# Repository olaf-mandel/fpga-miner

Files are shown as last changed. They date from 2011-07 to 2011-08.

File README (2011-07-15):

This project is concerned with mining Bitcoins via FPGAs.
For Details, see:

FPGA-Firmware:
http://forum.bitcoin.org/index.php?topic=9047.0

Hardware:
http://forum.bitcoin.org/index.php?topic=9047.0

The subdirectories (will at some unspecified point in the future) contain the
design files for the mining hardware, the firmware and the software.

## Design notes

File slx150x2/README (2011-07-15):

This directory contains the design for a hybrid FPGA board that can be
used both stand along as well as together with a packplane. The board
features two Xilinx Spartan 6 XC6SLX150-3FGG484C and one TI MSP430F55xx
MCU.

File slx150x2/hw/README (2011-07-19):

This directory is reserved for the hardware design.

Current contents:

* FPGAcomp.lib    : Eagle library containing custom components for design
* pcbcart.dru     : Eagle design rules file applied to the board
* FPGA_pin_demo.* : A design with two XC6SLX150 in the FGG484 package. No
                    power supply, interface logic or connectors.

The FPGA_pin_demo shows how to connect the different parts of the FPGA and
routes all signals on a 4-layer PCB. The minimum sizes are taken from the
discussion on the forum.

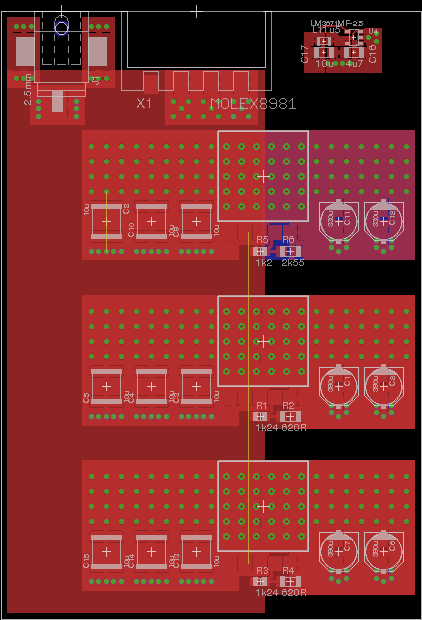
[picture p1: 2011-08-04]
slx150x2/hw/PSU.png

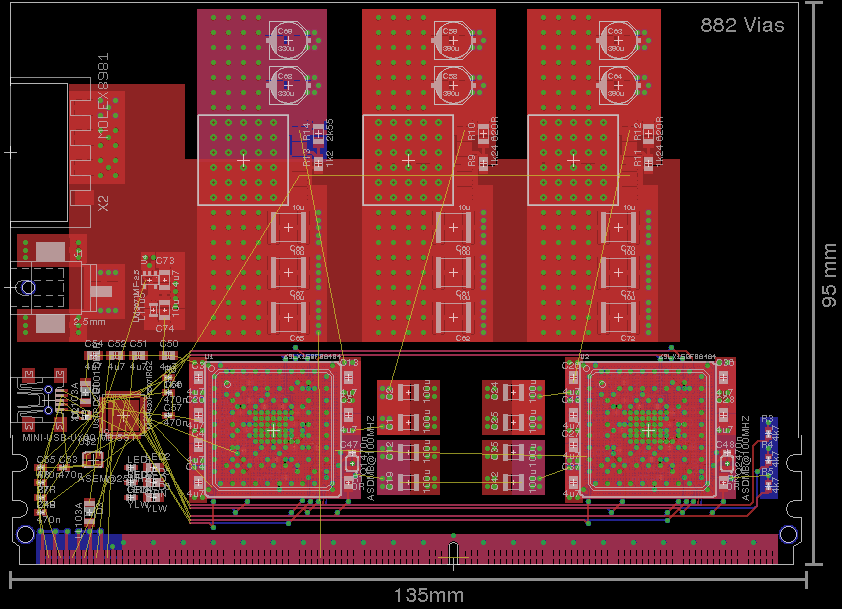
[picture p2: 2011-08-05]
slx150x2/hw/merged.png

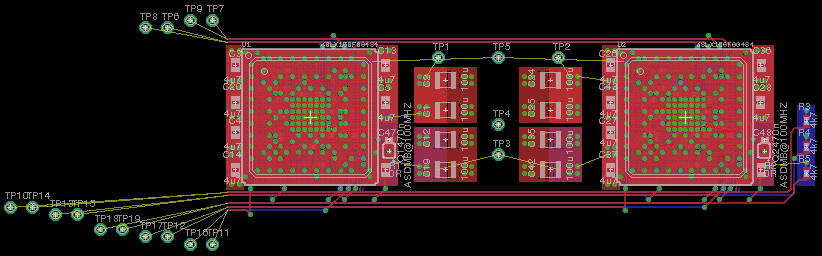
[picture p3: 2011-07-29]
slx150x2/hw/FPGA.png

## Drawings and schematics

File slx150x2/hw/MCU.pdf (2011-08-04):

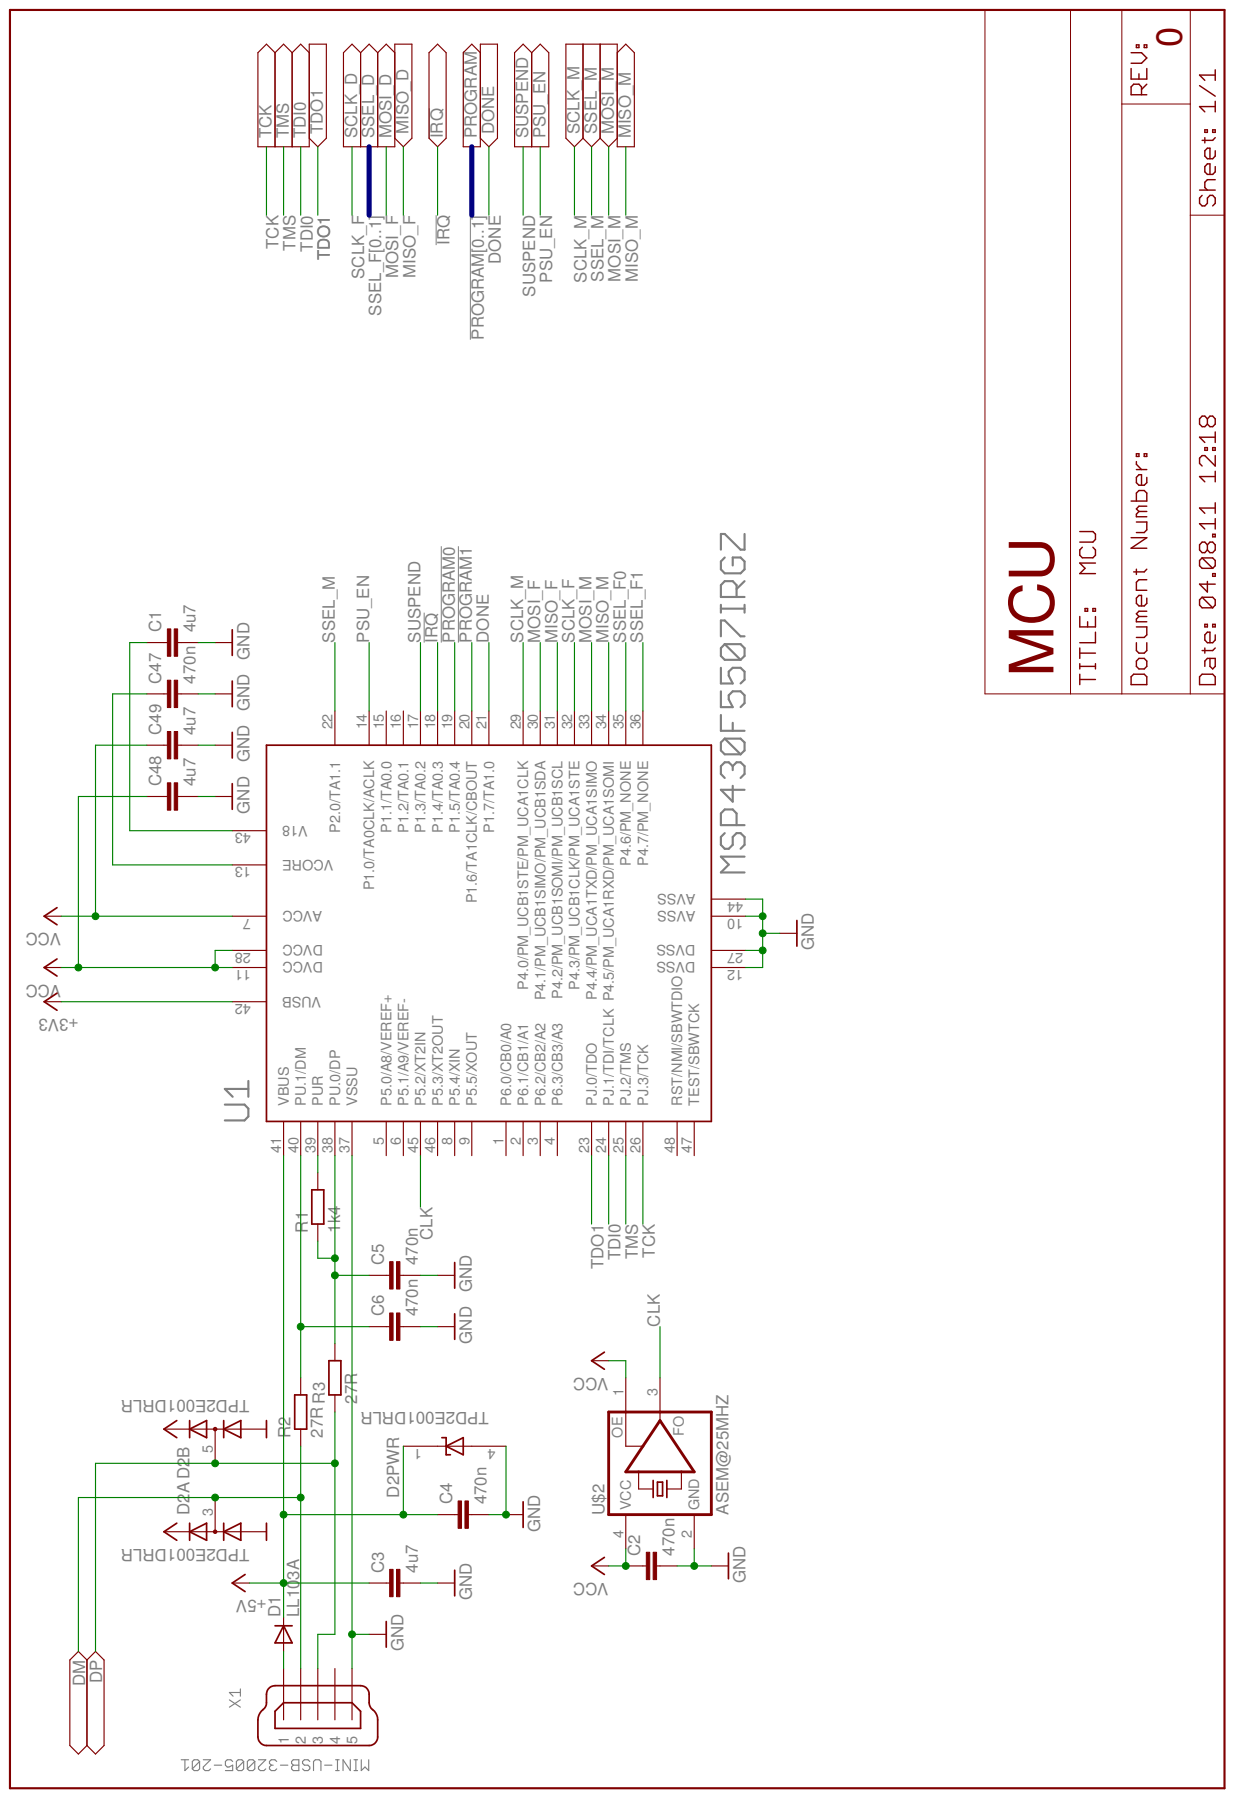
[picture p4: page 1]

470n 4u7 4u7 1k4 ASEM@25MHZ GND GND GND GND 4u7 GND CCV CCV GND GND CCV 470n CCV 4u7 GND 470n GND LL103A 27R 27R 470n GND 470n GND RL RD100E2 DPT RL RD100E2 DPT RL RD100E2 DPT 3V3+DMDP TCK TMS TDI0 TDO1 SCLK_D SSEL_D MOSI_D MISO_D IRQ PROGRAM DONE SUSPEND PSU_EN MISO_M SSEL_M SCLK_M MOSI_M V5+ P6.0/CB0/A0 1 P6.1/CB1/A1 2 P6.2/CB2/A2 3 P6.3/CB3/A3 4 P5.0/A8/VEREF+ 5 P5.1/A9/VEREF- 6 CCVA 7 P5.4/XIN 8 P5.5/XOUT 9 SSVA 01 CCVD 11 SSVD 21 EROCV 31 P1.0/TA0CLK/ACLK 14 CCVD 82 SSVD 72 PJ.3/TCK 26 PJ.2/TMS 25 PJ.1/TDI/TCLK 24 PJ.0/TDO 23 P2.0/TA1.1 22 P1.7/TA1.0 21 P1.6/TA1CLK/CBOUT 20 P1.5/TA0.4 19 P1.4/TA0.3 18 P1.3/TA0.2 17 P1.2/TA0.1 16 P1.1/TA0.0 15 P4.0/PM_UCB1STE/PM_UCA1CLK 29 P4.1/PM_UCB1SIMO/PM_UCB1SDA 30 P4.2/PM_UCB1SOMI/PM_UCB1SCL 31 P4.3/PM_UCB1CLK/PM_UCA1STE 32 P4.4/PM_UCA1TXD/PM_UCA1SIMO 33 P4.5/PM_UCA1RXD/PM_UCA1SOMI 34 P4.6/PM_NONE 35 P4.7/PM_NONE 36 VSSU 37 PU.0/DP 38 PUR 39 PU.1/DM 40 VBUS 41 BSUV 24 81V 34 SSVA 44 P5.2/XT2IN 45 P5.3/XT2OUT 46 TEST/SBWTCK 47 RST/NMI/SBWTDIO 48 C47 C48 C49 12345 R1 42 3 U$2 GND VCC 1 FOOE C1 C2 C3 C4 D1 R2 R3 C5 C6 D2A 3 D2B51 4 D2PWR PROGRAM[0..1] SSEL_F[0..1] CLK CLK TCK TCK DONE DONE TMS TMS TDI0 TDI0 TDO1 TDO1 IRQ IRQ SUSPEND SUSPEND PSU_EN PSU_EN SCLK_F SCLK_F MOSI_F MOSI_F MISO_F MISO_F SSEL_M SSEL_M MOSI_M MOSI_M MISO_M MISO_M SCLK_M SCLK_M SSEL_F0 SSEL_F1 PROGRAM1 PROGRAM0 0 MCU

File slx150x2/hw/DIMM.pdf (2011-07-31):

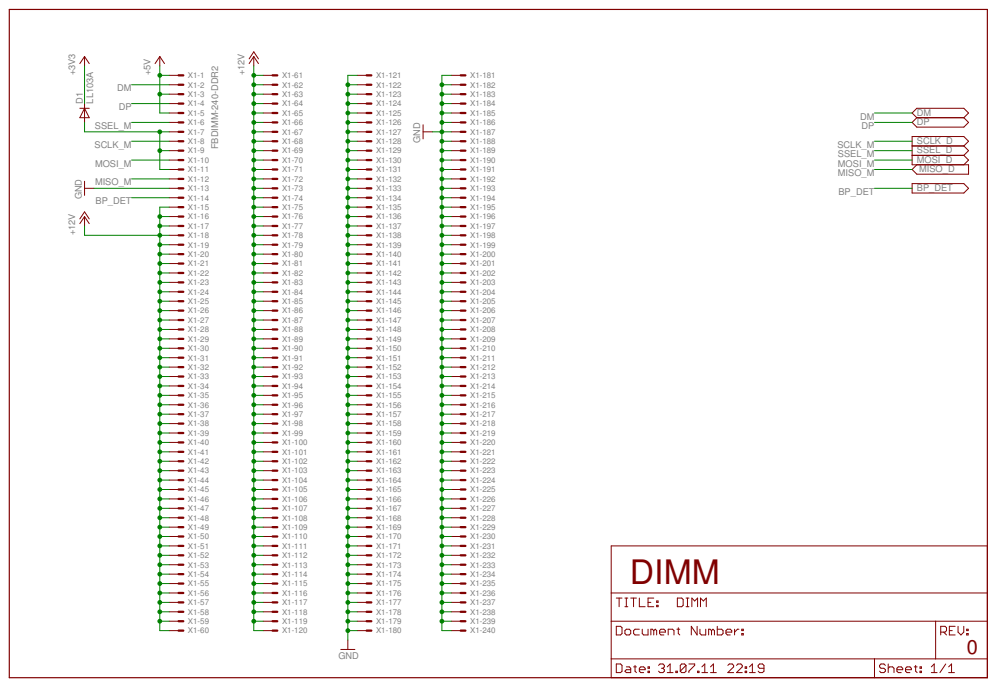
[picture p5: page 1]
FBDIMM-240-DDR2+12V; GND; SCLK_D SSEL_D M OSI_D MISO_D; DPDM; BP_DET; SSEL_M; SCLK_M; OSI_M; MISO_M; DIM

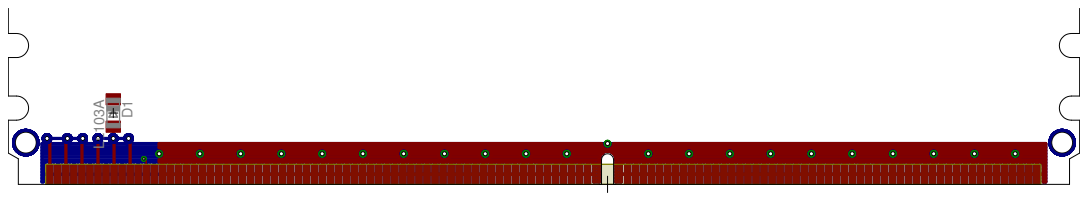
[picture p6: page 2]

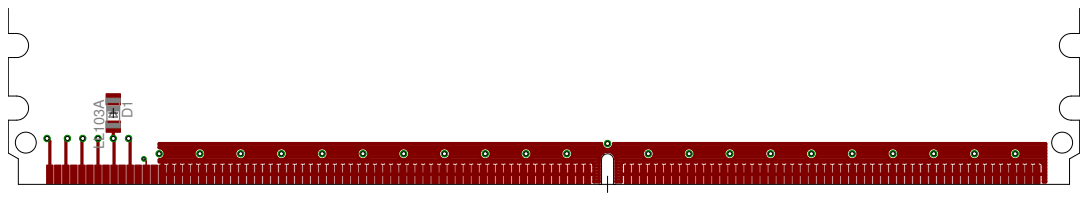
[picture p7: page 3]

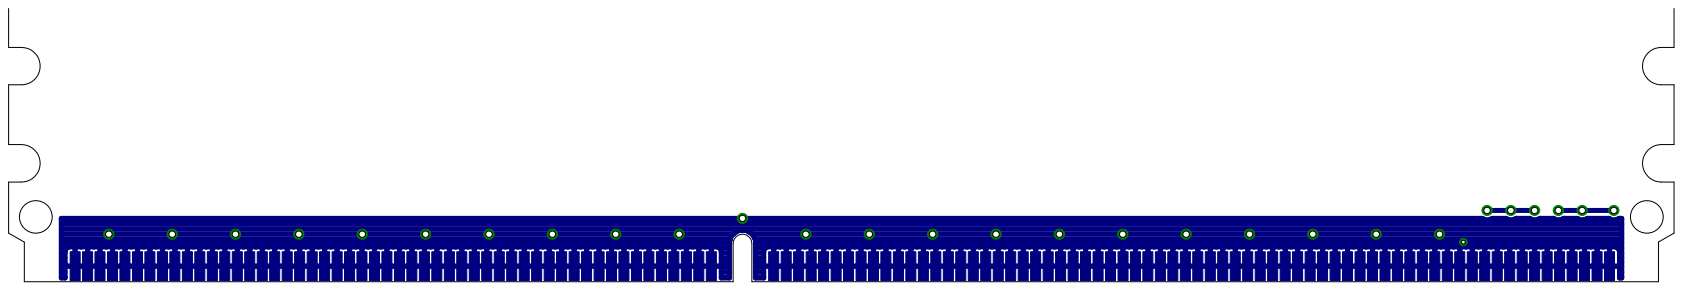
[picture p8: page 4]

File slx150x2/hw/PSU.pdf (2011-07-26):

2k55

## GND

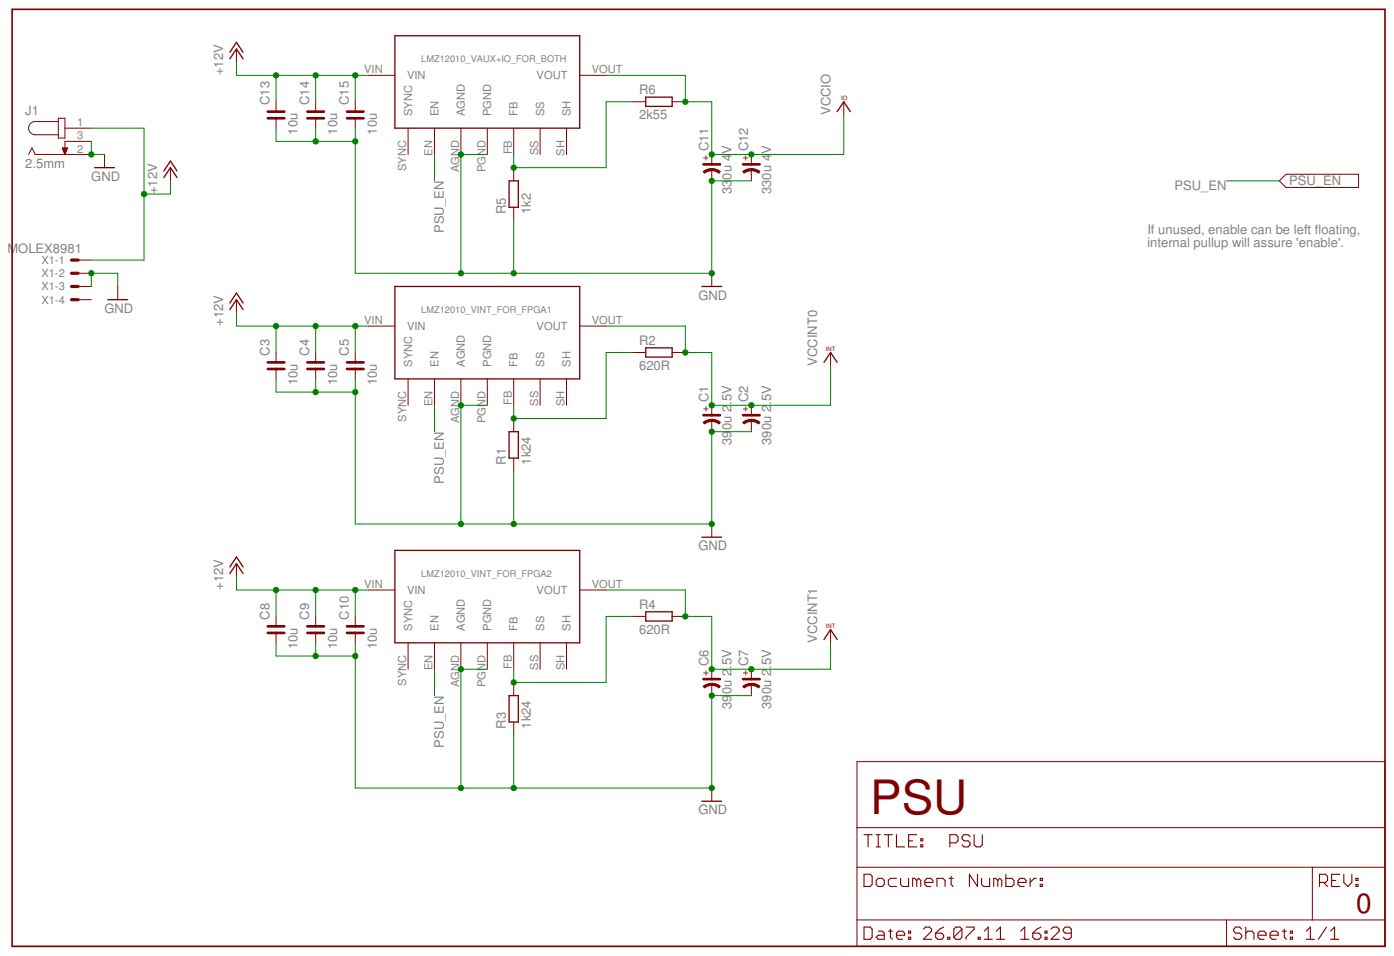
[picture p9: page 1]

If unused, enable can be left floating,
internal pullup will assure 'enable'.

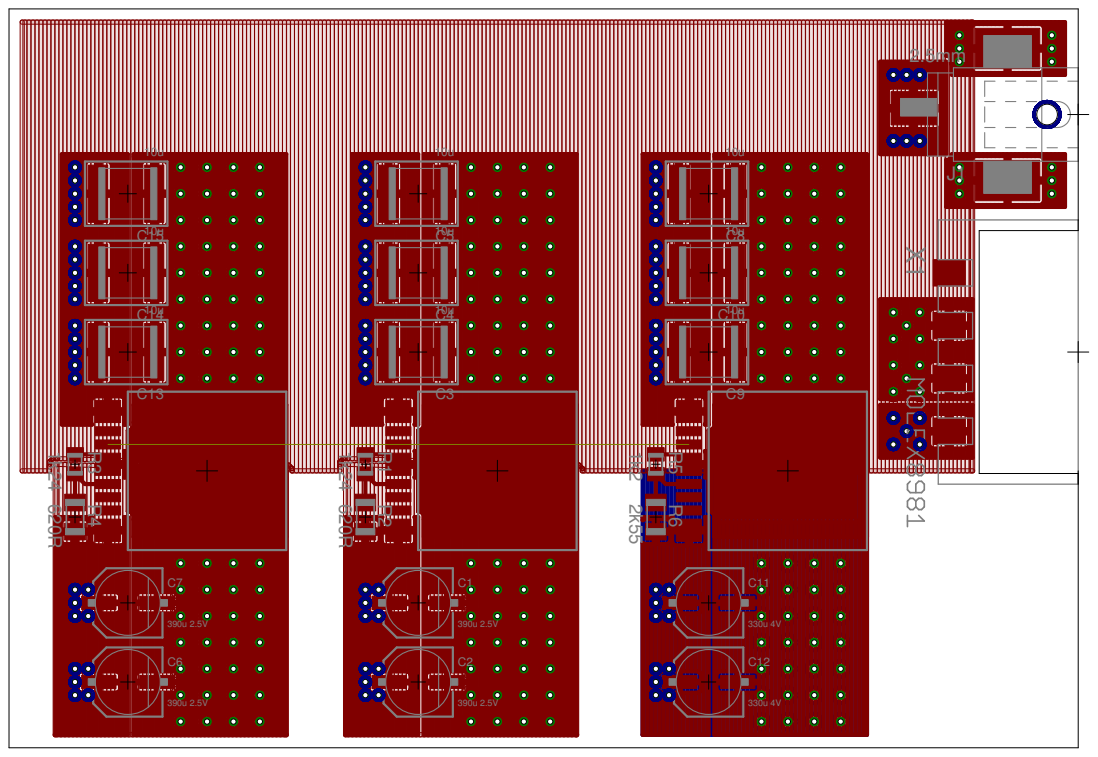
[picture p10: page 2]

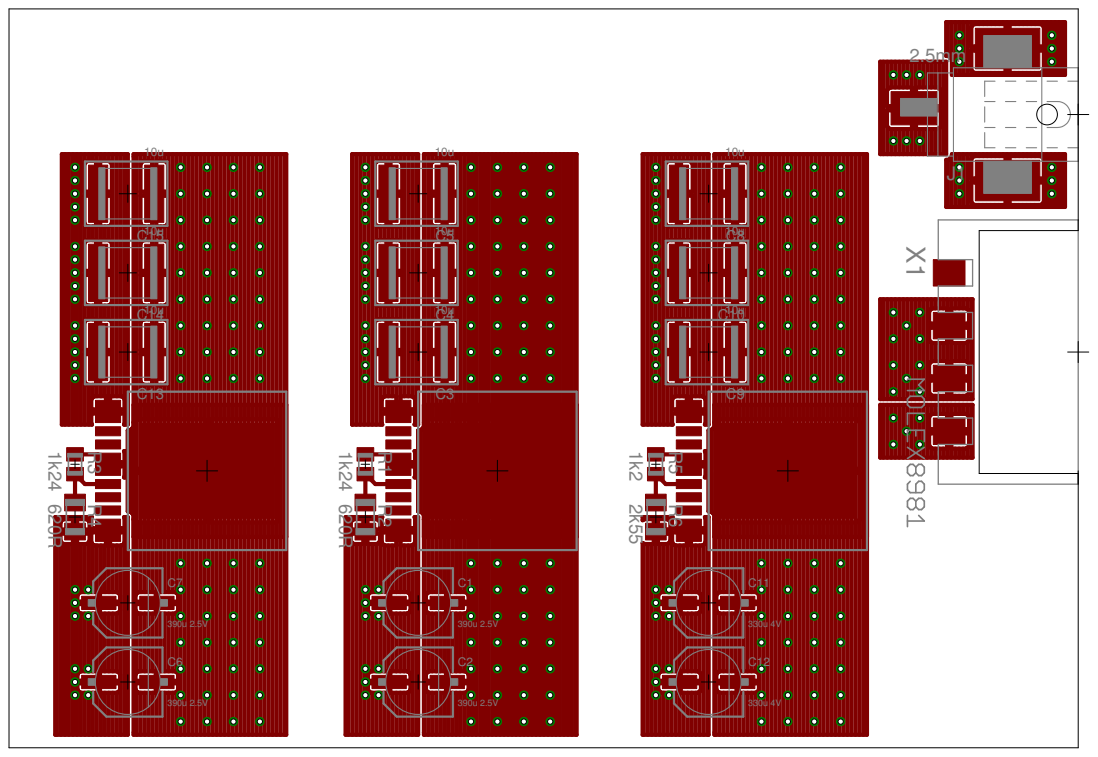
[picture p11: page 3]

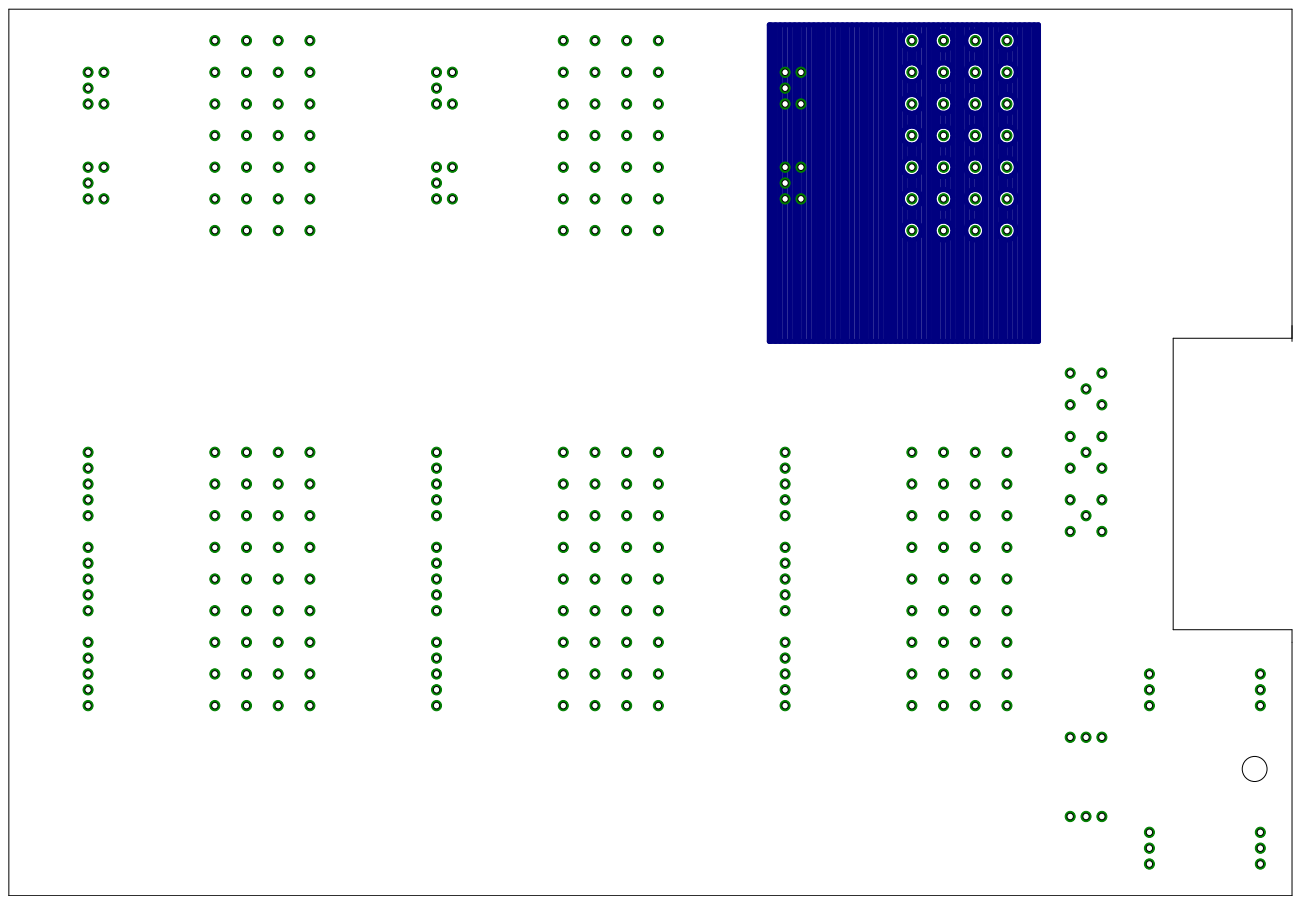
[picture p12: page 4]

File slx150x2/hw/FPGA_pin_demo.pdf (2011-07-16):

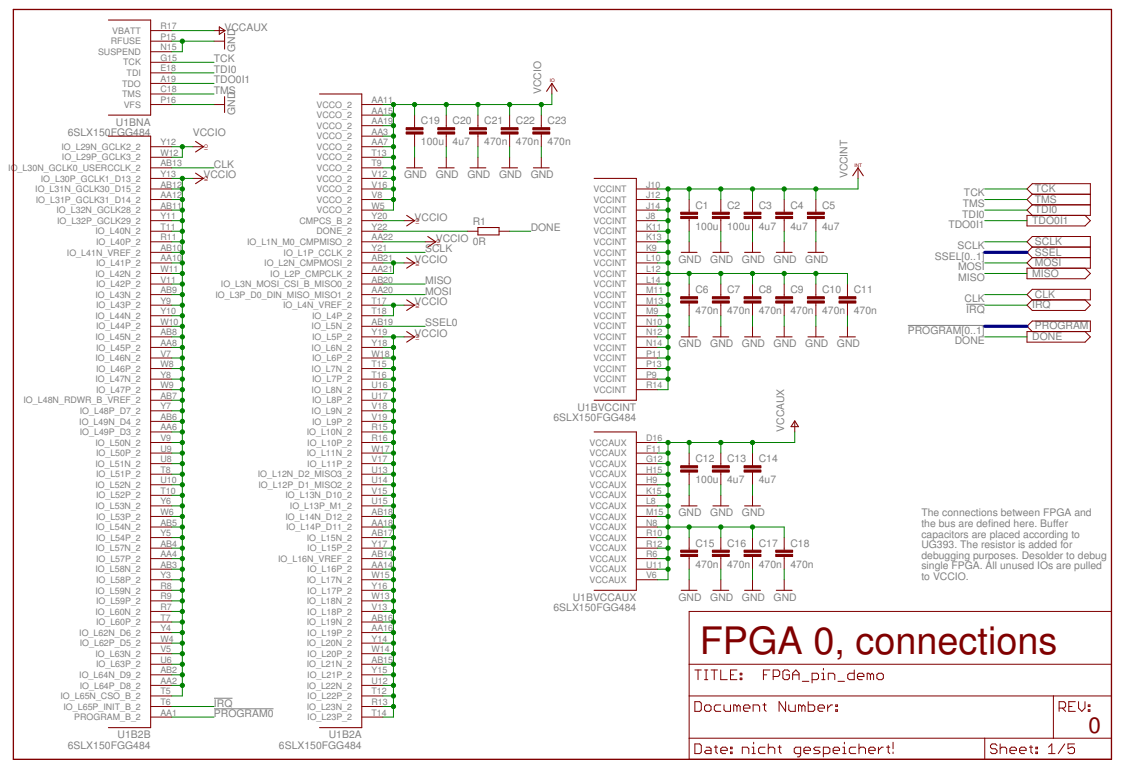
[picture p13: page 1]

GND GND GND GND GND

VCCIO

GND GND

GND GND GND

The connections between FPG
the bus are defined here. Buffer capacitors are placed according to UG393. The resistor is added for debugging purposes. Desolder to debug

A. All unused IOs are pulled

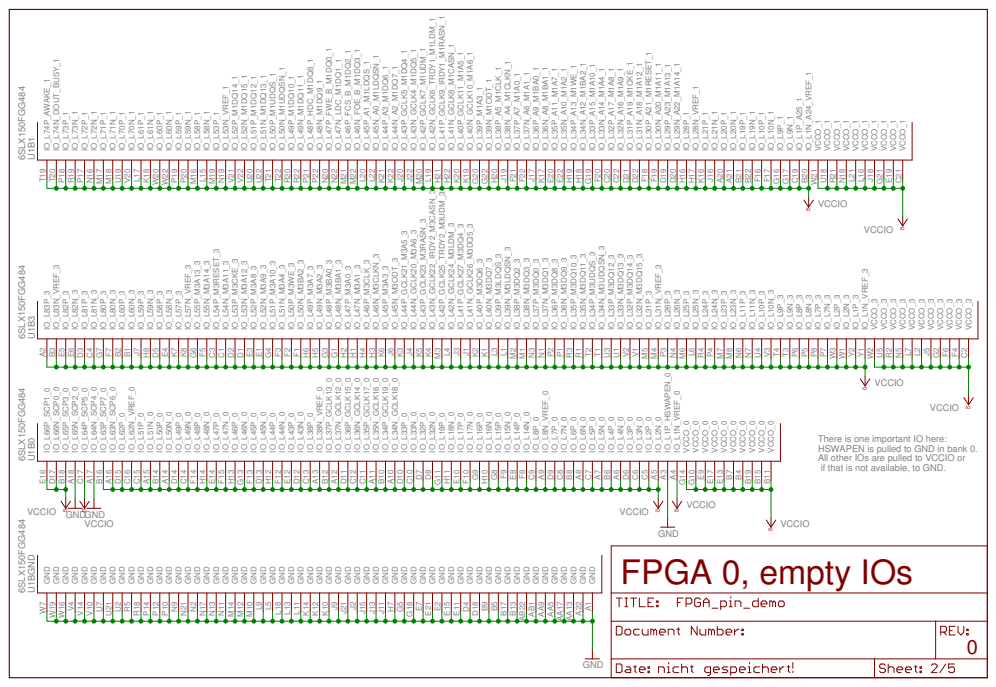
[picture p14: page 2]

There is one important IO here: HSW
APEN is pulled to GND in bank 0. All other IOs are pulled to VCCIO or

if that is not available, to GND. VCCIO

L9 GND M10 GND M12 GND M14 GND

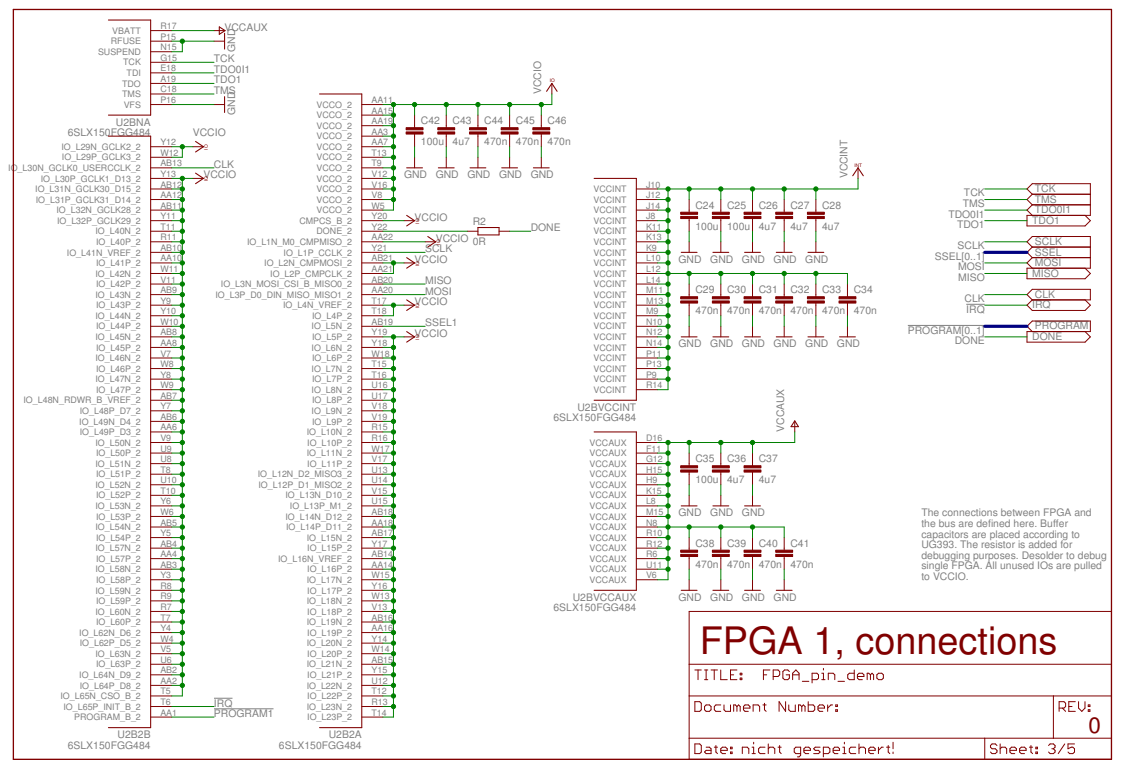
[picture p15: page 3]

GND GND GND GND GND

VCCIO

GND GND

GND GND GND

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

A. All unused IOs are pulled

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

if that is not available, to GND. VCCIO

L9 GND M10 GND M12 GND M14 GND

# TP1 TP2 TP3 TP4 TP5 TP6 TP7 TP8 TP9



C35 C³⁶ C³⁷ C³⁸ C³⁹ C⁴⁰ C⁴¹

C19 C20 C21 | | C42 C43 C44
100u | | 100u
4u7 | | 4u7

C12 C¹³ C¹⁴ C¹⁵ C¹⁶ C¹⁷ C¹⁸

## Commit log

2011-07-16 slx150x2, hw: added demo design containing 2 FPGAs
    The added design contains two XC6SLX150 in the FGG484 package. The design
    demonstrates the FPGA side of the system, the power supply and the interface
    are missing here. The FPGAs can be booted by JTAG and SPI and can communicate
    through SPI afterwards. All pins are connected and the design is fully routed.
    [FPGA_pin_demo.brd, FPGA_pin_demo.sch]
2011-07-19 New version of board, published 18.07.
    This board incorporates several changes:
    * Changed all unused pins to GND, pull HSWAPEN high for floating pins durings
    configuration
    * Use 4 layers
    * Added *.dru file for pcbcart service
    * Assign one layer each for the different signals:
    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
    [FPGA_pin_demo.brd, FPGA_pin_demo.sch]
2011-07-19 Fixed wrong connection to M1
    The mode selection pin M1 was connected to GND, must be VCC to ensure slave
    mode configuration.
    [FPGA_pin_demo.brd, FPGA_pin_demo.sch]
2011-07-20 Implemented last days suggestions
    Changed the schematic and board and implemented the following changes:
    * VCCINT is now split into two signals VCCINT0 and VCCINT1 for the two
    different FPGAs
    * VCCAUX is gone, merged with VCCIO
    * Layer 2 contains no polygon anymore
    * The different FPGAs are spaced further apart, polygons no longer touching
    * The termination resistors are folded to the back, reducing the size by half
    TODO:
    * Unfold the bus to not have several signals on top of each other
    * Merge with PSU (again) and MCU
    [FPGA_pin_demo.brd, FPGA_pin_demo.sch]
2011-07-22 Added supply layers, various
    Defined layers 2 and 15 as supply layers, removing them from the routing.
    This required merging VCCINT0 and VCCINT1 again. Additionally, it now was
    cheap to add a net NC for all unconnected pins of the FPGA.
    All big components are on the mil 25 grid, just the small caps on the back
    of the FPGAs are on a local 0.5mm grid around their FPGA.
    Unfolded the busses. Now they need more space but should be "safe". Moved
    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
    [FPGA_pin_demo.brd, FPGA_pin_demo.sch]
2011-07-22 Converted layer 15 back to polygons
    Converted the supply layer for VCCINT back to polygons, which allow the
    use of different nets. Also, moved some decoupling caps closer to their
    respective via.
    [FPGA_pin_demo.brd, FPGA_pin_demo.sch]
2011-07-24 New DRU and rerouted accordingly
    Changed DRU to match the decision made on the forum. Rerouted the FPGAs
    accordingly (now using the top layer for some traces). Also removed the
    termination resistors as suggested on the forum. And redistributed the
    bus signals to take advantage of the layer 15 routing possibilities.
    [FPGA_pin_demo.brd, FPGA_pin_demo.sch]
2011-07-24 Renamed FPGA design files
    Renamed all FPGA_pin_demo.* files to reflect their changed status: they now
    represent the FPGA parts of the DIMM daughterboard. Also renamed the
    library file to a less specific name.
    [FPGA.brd, FPGA.sch]
2011-07-24 Added PSU parts
    The added power supply schematics and board layout are copied unmodified
    from Li Gangyi's dropbox folder.
    [PSU.brd, PSU.sch]
2011-07-24 Bugfixes and cosmetic changes to PSU design
    * Renamed power signal names (to VCCINT[01])
    * Changed connectors to SMD versions (includes part in library)
    * Explicitly added PSU_EN signal
    * Changed labeling of components (1.2K -> 1k2)
    * Changed paper format from letter to DIN-A4
    [PSU.brd, PSU.sch]
2011-07-26 Created symbols for VCCINT[01]
    Added corresponding symbols to the project.lbr library and used them
    in the FPGA files. Also replaced the older name of the library with the
    corrent one in the schematic.
    [FPGA.brd, FPGA.sch]
2011-07-26 Routed PSU
    Fixed the package of the PSU switchers (had two pads) and routed the
    PSU section.
    [PSU.brd, PSU.sch]
2011-07-27 Added 100MHz oscillator to FPGAs
    [FPGA.brd, FPGA.sch]
2011-07-27 Added vias below switchers in PSU section
    [PSU.brd, PSU.sch]
2011-07-28 Added second 100MHz oscillator
    The oscillators are now located close to their respective FPGAs.
    [FPGA.brd, FPGA.sch]
2011-07-28 Added SUSPEND signal to FPGAs
    [FPGA.brd, FPGA.sch]
2011-07-29 Added MCU design from O_Shovah
    [MCU.sch]
2011-07-29 Shrunk oscillator and resistors in FPGA design
    Added the ASDMB oscillators (2.5x2.0m^2) to the library and used
    those in the FPGA design. Also changed the size of the pull-up
    resistors to 1005 metric size.
    [FPGA.brd, FPGA.sch]
2011-07-31 Minor: Moved SUSPEND label in FPGA design
    [FPGA.sch]
2011-07-31 Complete rewrite of the MCU design
    The following changes were done:
    * Changed symbol to new entry in library, having better structure
    * Changed library and size of caps
    * Changed oscillator
    * Added USB filters and ESD protection according to SLAU278F
    [MCU.sch]
2011-07-31 Fixed name of MSP430 package: PT48 -> RGZ48
    [MCU.sch]
2011-07-31 Updated library after learning about technologies
    Changes made:
    * Started using the ? and * keywords in device names, changed several parts
    * Added the PT48 package to the MSP430F55*I part, added attributes
    * This causes an incompatible name change in the MSP430F55XX device:
    use the replace command
    * Added the LM3671 device
    [MCU.sch]
2011-07-31 Refinements on PSU section
    Changes:
    * Added 3.3V -> 2.5V PSU
    * Changed all devices to default libraries
    * This specifically includes changes to the CPOL parts: they were oriented
    the wrong way around
    [PSU.brd, PSU.sch]
2011-07-31 Small changes to MCU
    * Changed name of VUSB to +3V3 (by changing the supply symbol)
    * Removed +5V name (by deleting the supply symbol)
    * Named the two USB signals DM and DP
    * Added two V<-> symbols and routed them to DM and DP
    [MCU.sch]
2011-07-31 Created first DIMM connector layout
    * Changed distance to dimension in DRU (DIMM fingers get very close)
    * Repaired DIMM package and added suitable device
    * Drew schematic with minimal connections
    * Routed power connections
    [DIMM.brd, DIMM.sch]
2011-07-31 Changed names of SPI signals in DIMM
    [DIMM.brd, DIMM.sch]
2011-07-31 Copied in MCU design by O_Shovah
    [MCU.sch]
2011-07-31 Repaired MCU design
    There were several defective wires: not attached to pins and wrong names
    [MCU.sch]
2011-08-04 Updated LMU22010 in library and in PSU
    * Changed pin SMD pad sizes and count to match datasheet
    * Changed schematic symbol to have correct number of pins
    * Updated PSU schematic and board to use new device
    * Set SYNC pins to GND as per li_gangyi's instruction (and datasheet)
    [PSU.brd, PSU.sch]
2011-08-04 Renamed SPI bus to FPGAs and synced designs
    * Renamed the SPI bus to the FPGAs in the MCU section from *_D to *_F
    (F standing for FPGA)
    * Changed the names in the FPGA design to match these
    [FPGA.brd, FPGA.sch, MCU.sch]
2011-08-04 Finished MCU connection
    * Connected SPI clocks to multiplexed pins (CHECK THAT THIS IS USABLE!!!)
    * Connected all other signals to some GPIO
    [MCU.sch]
2011-08-04 Added BOM database made by fizzisist
    [project.tsv]
2011-08-05 Fixed LMZ22010 <-> LMZ12010 mixup
    * Renamed GND back to AGND and PGND in LMZ22010
    * Changed description and default device name for LMZ22010
    * Added an explicit LMZ12010 device and symbol to the library
    (the symbols have the same pin lications for easier exhanges)
    * Used the new LMZ12010 in the PSU design
    [PSU.brd, PSU.sch]
2011-08-05 Added script to update BOM database
    The script updateavail.sh (POSIX systems only) queries the distributors webpage
    for each part in the *.tsv file and adds columns for number of on-stock parts
    and prices for different price-breaks. The project.tsv file has been
    reformatted to match the expected input of this script.
    TODO: Currently supports only DigiKey as a supplier. Need to add Avnet support.
    [project.tsv]
2011-08-05 Added new version of fizzisist's project.tsv
    [project.tsv]
2011-08-05 Reformated project.tsv to match updateavail.sh
    [project.tsv]
2011-08-05 Finished updateavail script
    * updateavail.sh now works correctly with avnet
    * Merged in new version of the database from fizzisist
    * Changed the package for the FPGAs to what is being used
    * Added second supplier for the FPGAs and big switchers
    * Updated extended database: runtime = 45s
    [project.tsv]
2011-08-05 Switched to fizzisist version of the MCU
    Changes as given by fizzisist:
    * Changed USB connector to one that's available on Digikey.
    * Added LEDs. These aren't connected to anything yet, but they
    are placed in the schematic and the BOM database. I added options
    for red, yellow, and green, all in 0603 and 0805 packages. Later,
    we can delete the ones we don't want. We should use the same LEDs
    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
    [MCU.sch]
2011-08-05 Fixed minor bugs in PSU.brd
    * One via was not in the GND net
    * One cap was oriented the wrong way around
    [PSU.brd, PSU.sch]
